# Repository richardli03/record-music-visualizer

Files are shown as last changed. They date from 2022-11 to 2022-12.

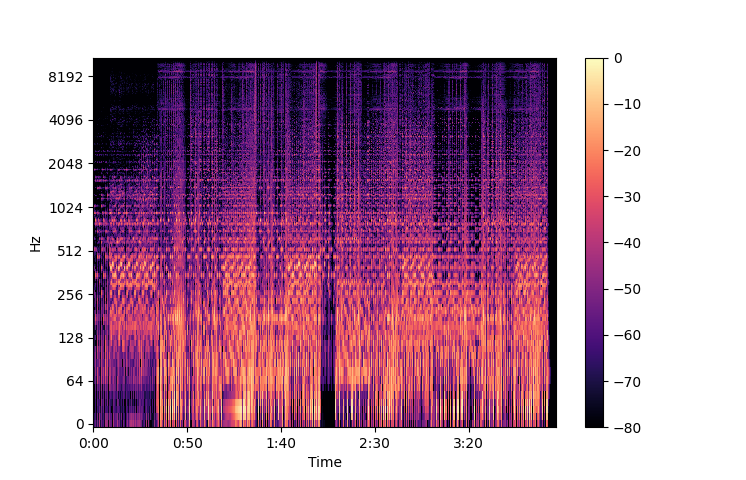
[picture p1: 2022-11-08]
assets/imgs/librosa/chromagraph.png

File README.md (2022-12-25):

# record-music-visualizer
Authors: Richard Li, Kat Canavan, Isha Goyal

A music visualizer inspired by a record player. The organization of this repository is split as follows. Check out [our website](https://olincollege.github.io/pie-2022-03/disco-divas/) which explains how we made this music visualizer in more detail.

## Assets

This folder contains the wav files that we process in our audio analysis workflow and the datasets that are generated (so that future generations with that song can use the csv instead of having to process the entire song). It additionally poses some images that we used to debug and showcase a log of our work. Check out the [README](assets/README.md) in this folder for a more in-depth explanation!

## Drivers

This folder contains all of the python code that we ran on the Raspberry Pi for our system. Specifically, the `main.py` file takes in a dataset + song long length and commands the system to move the DC and stepper motors such that they visualize the song.

## Firmware

This folder contains the Arduino C code that the Arduino uses to control the DC and Stepper Motors. 

## Scripts

This folder contains the python script `audio_analysis.py` that analyzes a song and returns a CSV that our driver script can use to generate a song visualization. `audio_analysis.py` utilizes the configuration file in `assets/` to dynamically perform analysis on different songs depending on the user's commands to the command line. The flags and corresponding functionality can be found by running `audio_analysis.py -h`

## Audio Processing 

We are creating an audio analysis suite from scratch using FFTs (Fast Fourier Transforms) over stretches of time.
Only dependences are NumPy, Pandas, Librosa, and Matplotlib

To run the audio processing, cd into `scripts` and run `python3 audio_analysis.py`

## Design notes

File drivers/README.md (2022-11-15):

All the code in this folder is hosted on the raspberry pi.

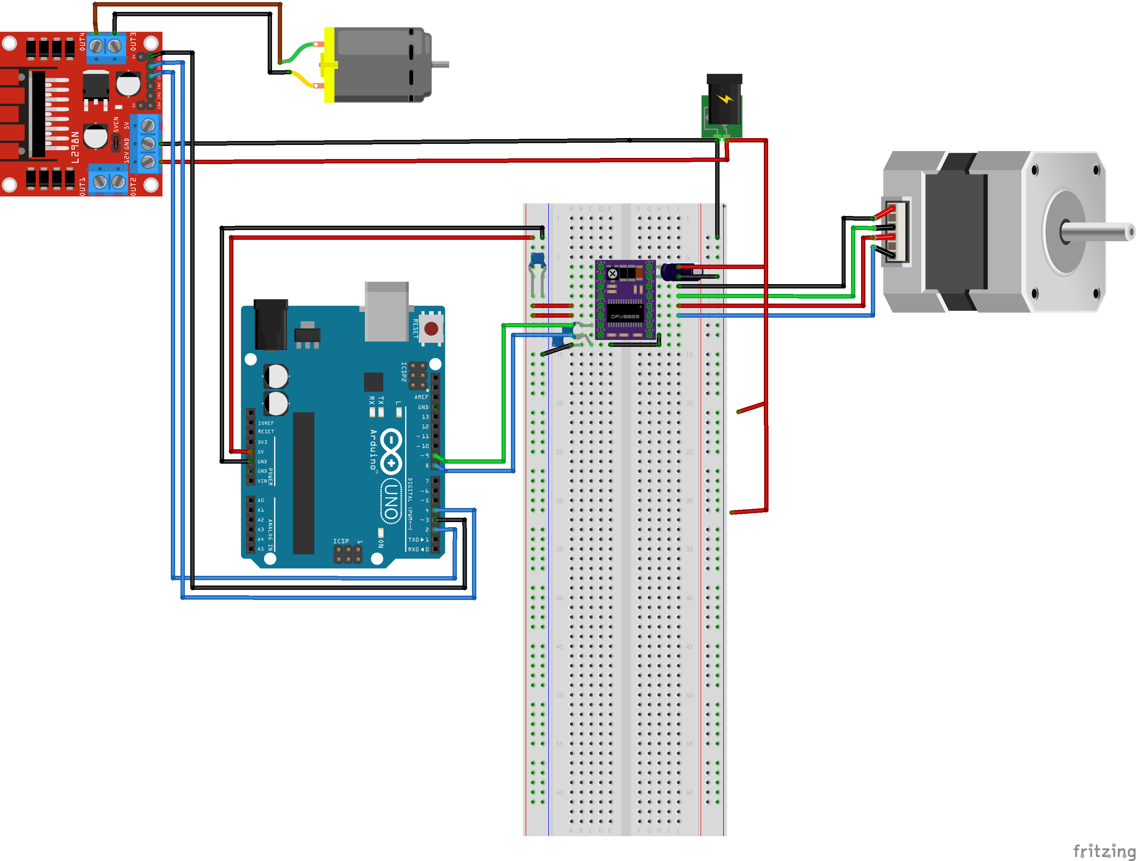
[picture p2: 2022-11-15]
schematic/Sprint2.png

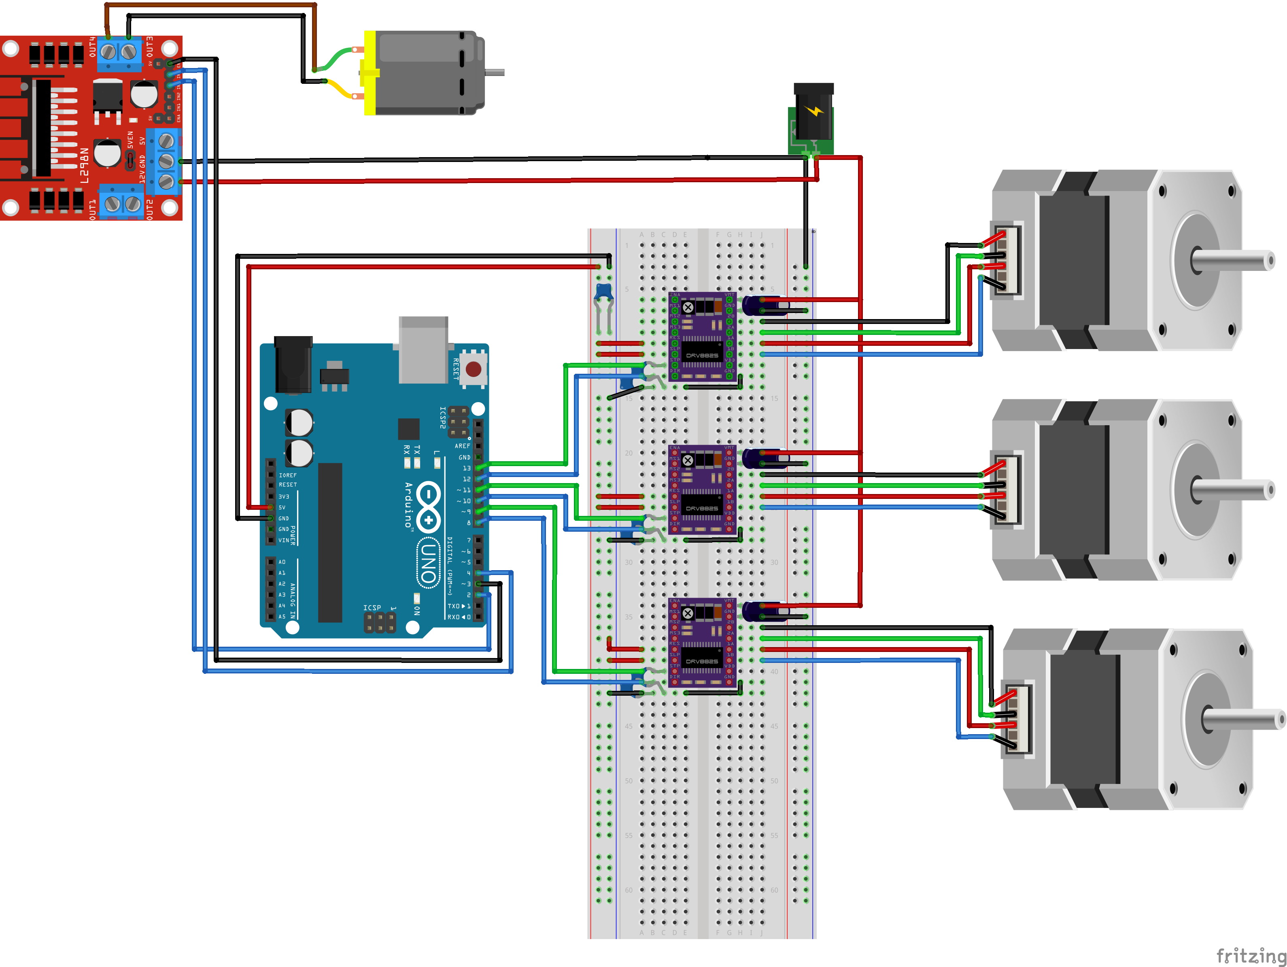
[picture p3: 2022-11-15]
schematic/schematic.png

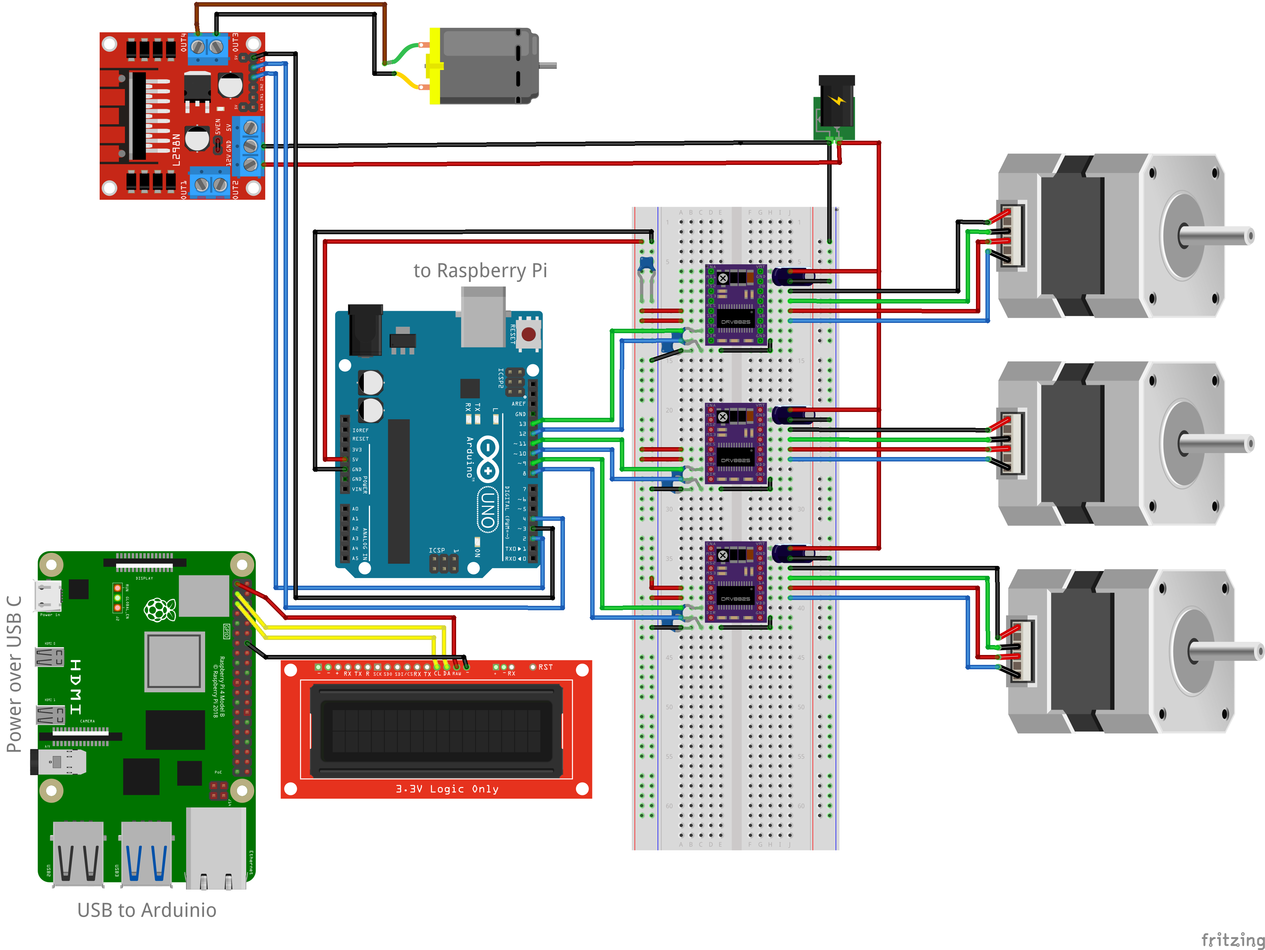
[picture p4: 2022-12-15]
schematic/schematic_final.png

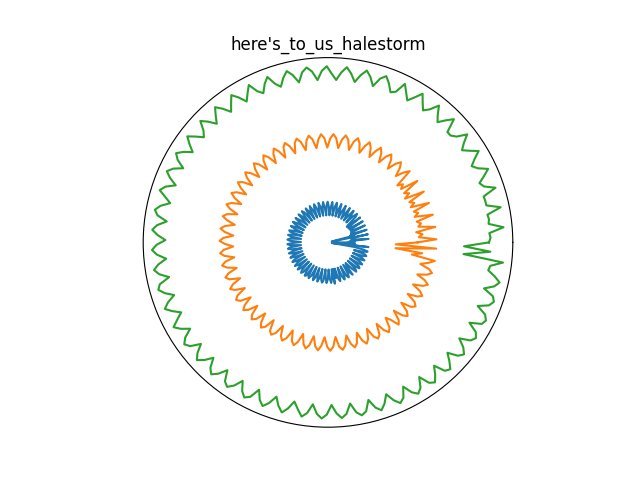
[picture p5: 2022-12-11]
assets/imgs/here's_to_us_osc.png

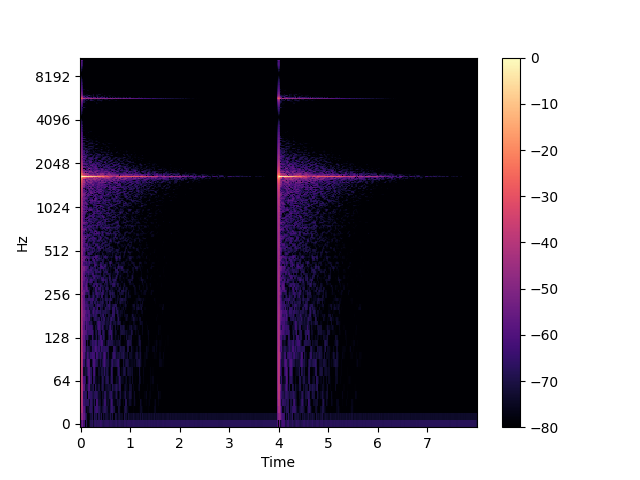
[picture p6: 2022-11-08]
assets/imgs/librosa/treble.png

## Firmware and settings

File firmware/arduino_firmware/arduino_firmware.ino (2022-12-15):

/* Arduino-side firmware for GPIO motor control
using DRV8825 stepper drivers and a L298N H-bridge for the DC motor.
pins listed below for sanity:

Stepper Motor A:
DIR (blue)  -> pin 8
STP (green) -> pin 9

Stepper Motor B:
DIR (blue)  -> pin 10
STP (green) -> pin 11

Stepper Motor C:
DIR (blue)  -> pin 12
STP (green) -> pin 13

DC Motor
IN 1 (mark) -> pin 4
IN 2 (blue) -> pin 2
ENB (black) -> pin 3 (pwm)
*/

#include <Arduino.h>
#include <L298N.h>
#include <AccelStepper.h>

// *** DC motor setup ***
const unsigned int IN1 = 4;
const unsigned int IN2 = 2;
const unsigned int EN = 3;
L298N DCmotor(EN, IN1, IN2);

// *** stepper motor setup ***
AccelStepper stepperA(AccelStepper::DRIVER, 9, 8);    // stp = 9, dir = 8
AccelStepper stepperB(AccelStepper::DRIVER, 11, 10);  // stp = 11, dir = 10
AccelStepper stepperC(AccelStepper::DRIVER, 13, 12);  // stp = 13, dir = 12

// buffer for target position-change before initial target reached
long next_target[3] = { 0, 0, 0 };

// *** START CODE ***

void setup() {
  // initialize serial communication
  Serial.begin(115200);

  // maximum speed in steps per second
  stepperA.setMaxSpeed(1100);
  stepperB.setMaxSpeed(1100);
  stepperC.setMaxSpeed(1100);
}


void loop() {

  // steppers need to take a step each loop and potentially update state
  stepperEachLoop(stepperA, 0);
  stepperEachLoop(stepperB, 1);
  stepperEachLoop(stepperC, 2);

  // check and process serial command if needed
  if (Serial.available() != 0) {
    // doesn't need to be a separate function but nice for organization
    SerialRead();
  }
}


void stepperEachLoop(AccelStepper &stepper, int index) {
  // things that have to happen or be checked for each stepper in each loop

  // if steps remaining until target step 1 step
  stepper.runSpeedToPosition();

  /* set speed to 0 when target position reached (accelstepper doesn't do this automatically,
  setting the speed to 0 doesn't physically do anything but it forces the program to 
  agree that the motor is stopped). Using setSpeed(0) instead of stop() because not using acceleration
  */
  if (stepper.targetPosition() == stepper.currentPosition()) {
    stepper.setSpeed(0);
  }

  // check if stepper has stopped and needs to set a new target
  if (stepper.speed() == 0 & next_target[index] != 0) {
    stepper.move(next_target[index]);  // set target as next target
    stepper.setSpeed(1100);
    next_target[index] = 0;  // reset next target
  }
}


void SerialRead() {
  String command;
  // commands start with '(' and end with ')' to avoid garbage characters
  if (Serial.read() == '(') {
    command = Serial.readStringUntil(')');
    Serial.println(command);
    // parse steps (always starts at index 2)
    long steps = command.substring(2, command.length()).toInt();

    // A stepper
    if (command.startsWith("sa")) {
      commandMove(stepperA, steps, 0);
    }
    // B stepper
    else if (command.startsWith("sb")) {
      commandMove(stepperB, steps, 1);
    }
    // C stepper
    else if (command.startsWith("sc")) {
      commandMove(stepperC, steps, 2);
    }
    // DC motor run with `drN` where N is speed between 0-255
    else if (command.startsWith("dr")) {
      unsigned short speed = command.substring(2, command.length()).toInt();
      DCmotor.setSpeed(speed);
      DCmotor.forward();
    }
    // stop DC motor with `ds`
    else if (command == "ds") {
      DCmotor.setSpeed(0);
      DCmotor.forward();
    }
  }
}

void commandMove(AccelStepper &stepper, long steps, int index) {
  // determine movement based on command and current motor state
  if (stepper.speed() == 0) {
    // move stepper `steps` steps
    stepper.move(steps);     // set relative target position
    stepper.setSpeed(1100);  // must set speed after moveTo to get rid of accl
  } else {                   // if stepper is currently moving
    next_target[index] = steps;
  }
}

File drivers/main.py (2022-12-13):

"""
turn the DC motor on and spin the servo for a few seconds
"""

from timeit import default_timer as timer
from send_serial import *
import pandas as pd
import time


class Stepper:
    def __init__(self, name):
        self._name = name
        pass
    
    def move(self, value):
        """
        As a reminder to me, the "value" is going to be a 
        rigid distance away from its "center line"

        Args:
            value (_type_): _description_
        """

        # stepper motor calibration equation
        move_amount_steps = (625 * (-value) + -7.23)  #from inches to steps
        
        if move_amount_steps < 0:
                move_amount_steps *= 0.87
                
        
        if self._name == "bass":
            stepper("a", int(move_amount_steps))
            return
            
        if self._name == "mid":
            stepper("b", int(move_amount_steps))
            return
            
        if self._name == "treb":
            stepper("c", int(move_amount_steps))
            return
    
    def __repr__(self) -> str:
        return f"Stepper motor {self._name}"

def compute_DC_speed(song_length) -> float:
    """
    Given some song length (in seconds), compute
    the speed of the DC motor necessary to make that happen
    """
    # line of best fit 
    if song_length > 100:
        motor_speed = 152 - 0.902*song_length + 0.00204*(song_length**2)
    else:
        motor_speed = 1334 - 27.5*song_length + 0.152*(song_length**2) 

    print(f"Current DC speed is {motor_speed}")

    return motor_speed

def theta_to_seconds(theta, song_length):
    """
    Given the length of the song and an angle, compute what 
    time should be equivalent to this angle.

    Args:
        theta (int): the angle in question, in degrees
        song_length (int): the length of the song
    
    Returns: 
        seconds: the number of seconds that should've passed to this theta
    """
    
    sec_per_r = song_length/6.283185307
    # sec_per_r = song_length/360
    return theta * sec_per_r


def create_song_data():
    song_data = pd.read_csv(INPUT_FILE).transpose()

    # Catch errors
    if song_data.empty:
        raise Exception("No song data found!")
        return 
    
    num_samples = list(song_data.columns)
    # Convert the theta column to how many seconds it should be before the thing is where it is.
    seconds_for_movement = pd.DataFrame([theta_to_seconds(song_data[sample][0], SONG_LENGTH) for sample in num_samples]).transpose()
    
    # Get rid of theta data and add in seconds data
    song_data.drop(["theta"], inplace= True, axis = 0)
    song_data = pd.concat([seconds_for_movement, song_data])
    return song_data, num_samples
    
    
def main():
    dc_off()
    
    # initialize stepper motors
    bass = Stepper("bass")
    mid = Stepper("mid")
    treble = Stepper("treb")

    # stepper calibration/initialization routine
    # sends each stepper to its initial position, assuming each starts
    # against its respective calibration block
    
    baseline_radii = [0.9, 2.8, 4.3] # inches
    blocks = [0, 1.5, 3.5] # length of the calibration blocks
    
    pos = [baseline_radii[i] - blocks [i] for i in range(3)]
    
    treble.move((1/0.9)* pos[2]) 
    time.sleep(1)
    mid.move((1/0.9)*pos[1])
    time.sleep(1)
    bass.move((1/0.9)*(pos[0]))
    time.sleep(1)
    
    song_data, num_samples = create_song_data()
    
    # debug = pd.DataFrame(columns = ["time", "bass","mid","treble"])
    print(song_data)
    
    current_pos = [0, 0, 0, 0]
    
    # Sleep before starting!
    print("ready to begin!")
    time.sleep(3)
    
    # start spinning the disk
    dc_speed(compute_DC_speed(SONG_LENGTH))  


    t_start = timer() # time since Jan 1, 1970 for timer purposes
  
    # current_time = 0
    
    for sample in num_samples:
        # Split the new row of values into their components
        next_sample = song_data[sample]
        vals = next_sample.to_list()
        seconds = vals[0]
        
        # # i think this should prevent the steppers from moving faster than we want them to. 
        # # may need to calibrate some stuff
        while timer() - (0.3 + seconds) < t_start:
            pass
        
        # Get bass, mid, treble positions, calculate change in position, and
        # move accordingly
        bass.move((vals[1]-current_pos[1])*STEPPER_SCALE)
        time.sleep(0.15)
        mid.move((vals[2]-current_pos[2])*STEPPER_SCALE)
        time.sleep(0.15)
        treble.move((vals[3]-current_pos[3])*STEPPER_SCALE)  
        
        # print(f"{seconds-current_time} seconds")
        # print(f"moving {(625 * (-(vals[2]-current_pos[2])) + -7.23)*STEPPER_SCALE} steps")
       
        # Add movement commands to a debug file 
        # debug.loc[len(debug)] = [seconds-current_time, vals[1]-current_pos[1],vals[2]-current_pos[2], vals[3]-current_pos[3]]

        # current_time = seconds
        current_pos = vals # stores current values 
    
    # debug.to_csv("debug4.csv")
    dc_off()

if __name__ == "__main__":
    SONG_LENGTH = 154 # s 
    INPUT_FILE = "datasets/love_story.csv"
    STEPPER_SCALE = 0.45
    main()

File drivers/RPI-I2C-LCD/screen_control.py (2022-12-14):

# import the CircuitPython board and busio libraries
import board
# Enable I2C (Qwiic) communication
from sparkfun_serlcd import Sparkfun_SerLCD_I2C
i2c = board.I2C()
serlcd = Sparkfun_SerLCD_I2C(i2c)

serlcd.set_backlight(10040319) # purple

# send command
serlcd.write("   Disco Diva   ")

# uncomment the following for the first run

# armsDown = [
# 	0b00100,
# 	0b01010,
# 	0b00100,
# 	0b00100,
# 	0b01110,
# 	0b10101,
# 	0b00100,
# 	0b01010]
# armsUp = [
# 	0b00100,
# 	0b01010,
# 	0b00100,
# 	0b10101,
# 	0b01110,
# 	0b00100,
# 	0b00100,
# 	0b01010]

# serlcd.create_character(1, armsUp)
# serlcd.create_character(0, armsDown)

# dancing dude
# while True:

# 		serlcd.set_cursor(1,0) # column, row
# 		serlcd.write_character(0) # print little man, arms down
# 		time.sleep(0.2)

# 		serlcd.set_cursor(1,0) # column, row
# 		serlcd.write_character(1) # print little man, arms up
# 		time.sleep(0.2)

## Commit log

2022-10-24 added sample song
2022-10-27 updated README with current libraries
2022-11-02 Generalized code
    Made some changes so the code will work for a song of any length.
    [bass_data.csv, mid_data.csv, treble_data.csv]
2022-11-03 Add Raspberry Pi branch
2022-11-06 Add stepper test
2022-11-07 Create new branch
    To read freq data from csv so it runs faster. Started programming a basic log split.
    [all_freq_data.csv]
2022-11-08 added another sample test file
2022-11-08 deleting tester csv files
    [bass_data.csv, mid_data.csv, treble_data.csv]
2022-11-08 Create streamline branch and library file
    Started working on the streamlining. Created a library file and moved things over. Still a couple of conflicts to resolve.
2022-11-10 Add arduino firmware
2022-11-11 Stepper over serial
2022-11-11 Add record-style visualization
    Working version of the function to visualize the bass, mid, and treble volumes on a circle, like our physical mechanism.
    [all_freq_data.csv]
2022-11-11 Add DC motor test
2022-11-11 Control DC and 1 stepper over serial
2022-11-11 Final streamline commit.
    Everything currently works to make the baseline visualization.
    Will be merged with main.
    [all_freq_data.csv, halved_data.csv]
2022-11-11 deleting test csv!
    [all_freq_data.csv]
2022-11-11 Removed grid
    Made some small changes:
    1) Removed gridlines and changed the underlying way we're plotting polar to make it simpler.
    2) Small changes to the way it handles CSVs and making them or not.
    [all_freq_data.csv]
2022-11-12 Add schematic
    [Sprint2.fzz]
2022-11-12 schmatic planning
    [schematic.fzz]
2022-11-13 Add Drivers
2022-11-17 added initial parser framework
2022-11-18 Added features to create CSV
    CSV contains the position for each motor with respect to the degrees along the circle (which represents time).
    [pos_data.csv]
2022-11-18 Use radius_variation for position data
    Changed from having the CSV give raw positions to giving the variation from the average.
    [pos_data.csv]
2022-11-18 integrated stepper objects, waiting for calibration data
    [pos_data.csv]
2022-11-18 Debugging
    Did some debugging so that all the frequencies aren't overlapping anymore. Currently in a working state (no error messages), but is still not doing quite what we want.
2022-11-18 Degrees now has num_samples subdivisions
    As opposed to being the size of the number of samples in the bass frequency spectrum (works with a change made above to make the freq_spread linspace also be based on num_samples).
2022-11-19 Working version of graph with scaled data
    Makes each band go from -1 to 1 inch from its baseline. Currently a working version.
2022-11-20 Working (but not good) oscillations
    Currently all three ranges show up on different graphs. Also the oscillations are too dense, so it shows up as one filled in shape. It works and produces a graph though.
2022-11-20 Changed sample length. Oscillations working well.
    Changing sample length changes density of oscillations and really affects the visual you get. Played around with some of that. This is a working version of oscillations.
2022-11-29 Add all steppers
2022-11-29 Tested out different songs and oscillations
    Didn't make major changes. Just added titles to graphs, started saving figures, and added different audio files to test.
    [pos_data.csv]
2022-11-29 added framework parser code with calibration equations
2022-12-01 Control 1 motor over serial
2022-12-01 Add control for 3 steppers
2022-12-01 3 steppers move at the same time!
2022-12-02 testing setup
    [pos_data.csv]
2022-12-05 added in new two-phase DC motor calibration and some new datasets
    [bass.csv, herestous.csv]
2022-12-10 Refactor and improve buzzing bug
    [arduino_firmware.ino]
2022-12-10 Created stepper initialization sequence
    Sends each of them to their starting position. Debugged a couple of calibration things.
2022-12-12 Don't stop on command interrupt
2022-12-12 Calibration works, the waves do not. It does currently move the stepper motors, but it has excessive drift.
    [main.py]
2022-12-12 added stepper calibration
2022-12-12 added updated config files + created datafiles
    [bass.csv]
2022-12-13 added new datasets for reuseability
    [bass.csv, love_story.csv]
2022-12-13 Back to a point where herestous works.
    [dummyDataPIE.csv]
2022-12-13 Created dummy data file (not working).
    It does not make the motors move.
    [dummyDataPIE.csv]
2022-12-13 added theta to dummy data + fixed timer on main
    [dummyDataPIE.csv, herestous.csv]
2022-12-13 cleaned scripts folder, removed debug CSVs
    [all_freq_data.csv, pos_data.csv]
2022-12-13 created functional motor movement script
2022-12-14 Add I2C for screen
2022-12-15 Update schematic
    [schematic.fzz]
